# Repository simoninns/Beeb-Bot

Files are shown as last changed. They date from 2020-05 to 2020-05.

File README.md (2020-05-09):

# Beeb-Bot

Beeb-Bot is a fully open-hardware recreation of the 1983 Economatics BBC Buggy robot. The robot was originally designed as a STEM educational tool to accompany the Acorn BBC Microcomputer that was popular in schools at the time.

For full details of the project including printing and assembly instructions, please see the project Wiki:

[Beeb-Bot Project Wiki](https://github.com/simoninns/Beeb-Bot/wiki)

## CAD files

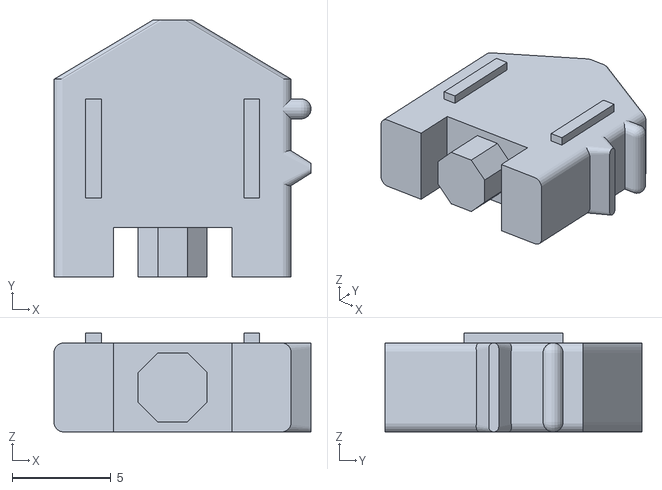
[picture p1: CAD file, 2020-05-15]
stl/mini_switch_plunger.stl
13.0 x 13.0 x 5.00

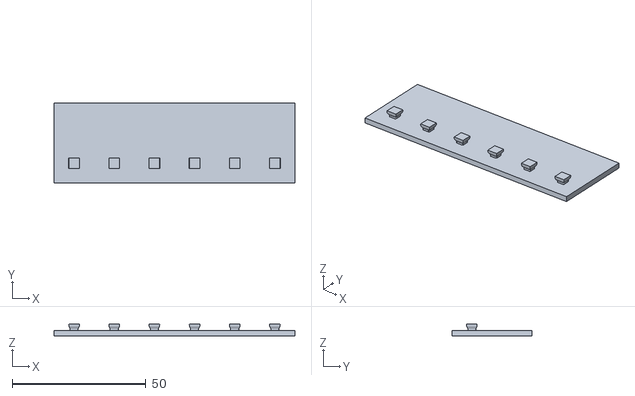
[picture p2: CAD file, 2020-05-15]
stl/plate_sr_30x90mm.stl
90.0 x 30.0 x 4.38

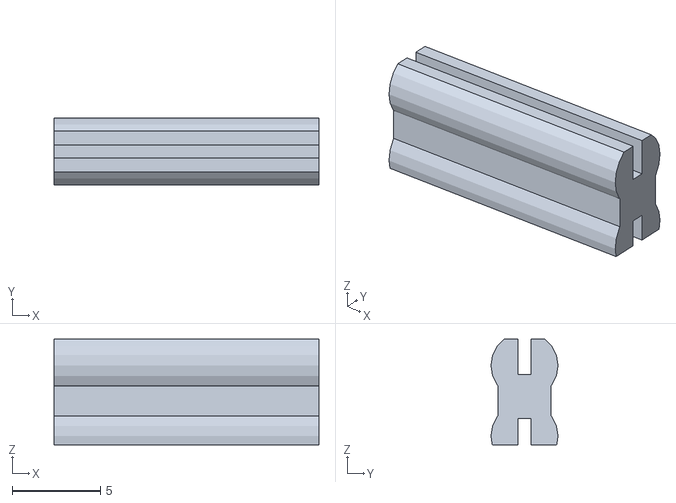
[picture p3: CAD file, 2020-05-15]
stl/link_15mm.stl
15.0 x 3.80 x 6.00

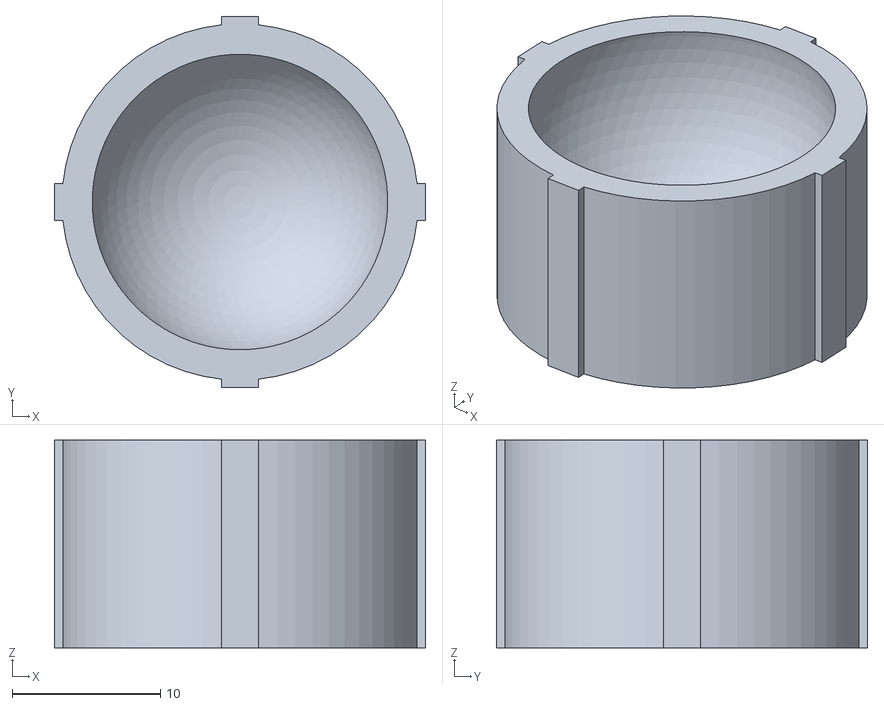
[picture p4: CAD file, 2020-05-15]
stl/ball_caster_top.stl
25.0 x 25.0 x 14.0

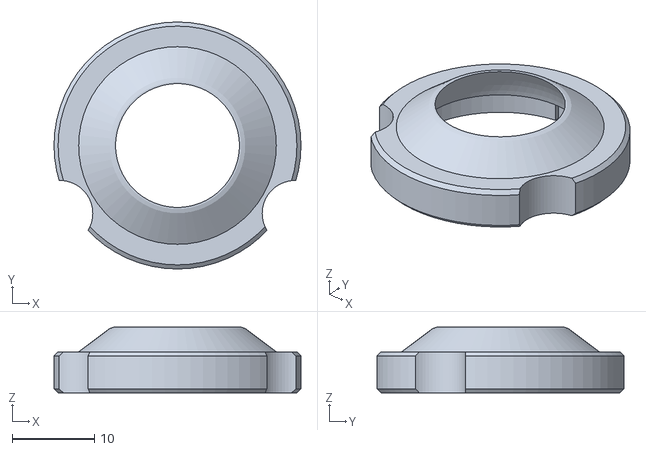
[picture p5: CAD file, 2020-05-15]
stl/ball_caster_base.stl
30.0 x 30.0 x 8.00

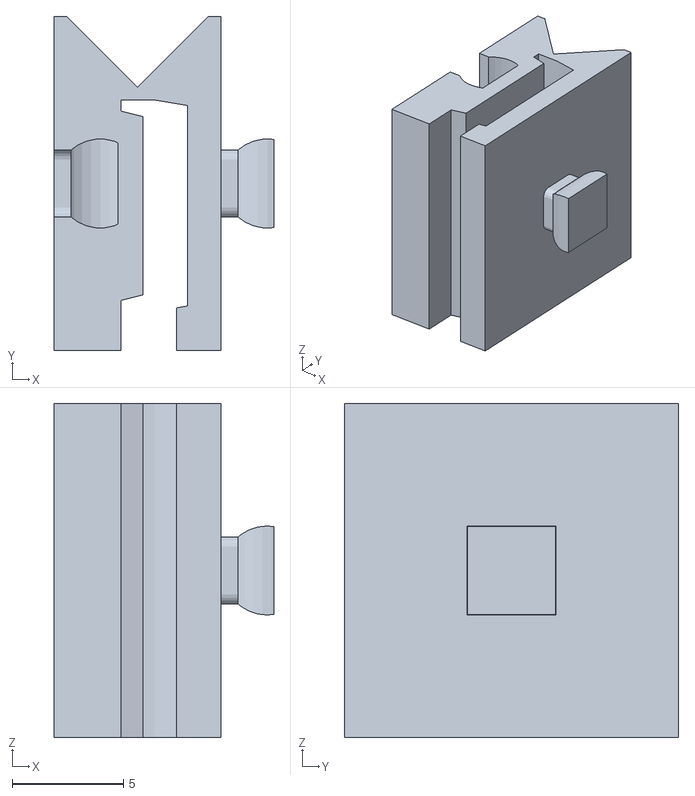
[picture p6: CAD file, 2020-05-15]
stl/hinge_small.stl
9.88 x 15.0 x 15.0

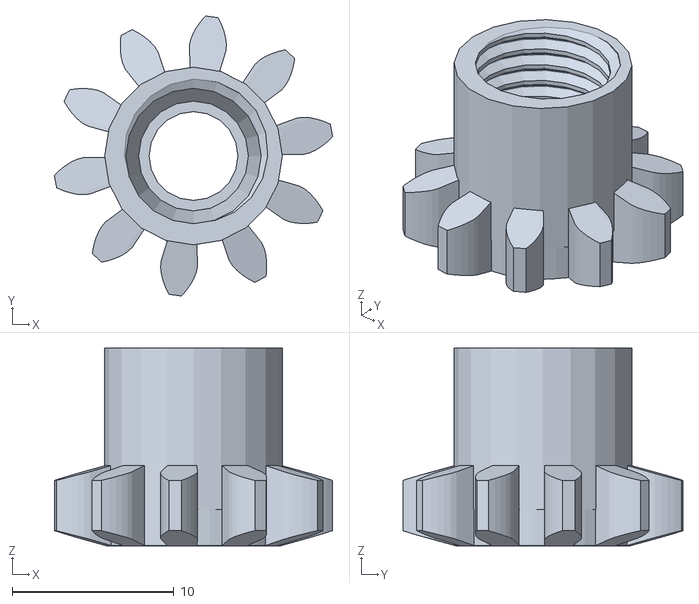
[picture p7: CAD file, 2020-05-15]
stl/nema17_cog_wheel_top.stl
17.2 x 17.3 x 12.2

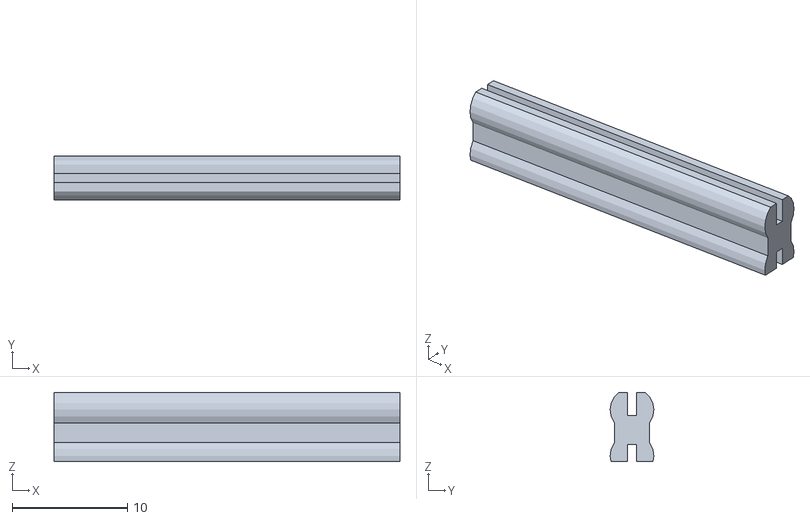
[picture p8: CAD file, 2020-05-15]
stl/link_30mm.stl
30.0 x 3.80 x 6.00

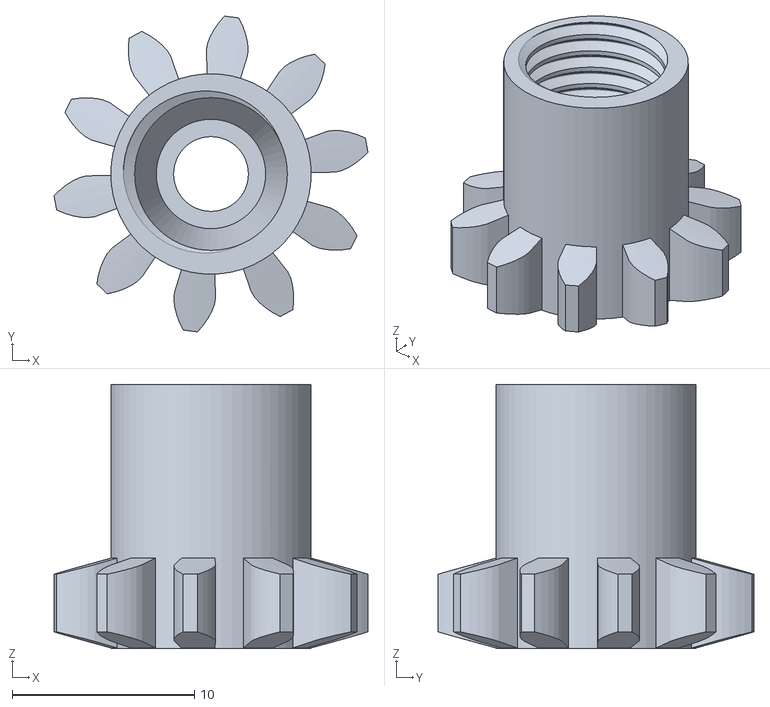
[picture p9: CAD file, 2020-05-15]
stl/philips_cog_wheel_top.stl
17.2 x 17.3 x 14.5

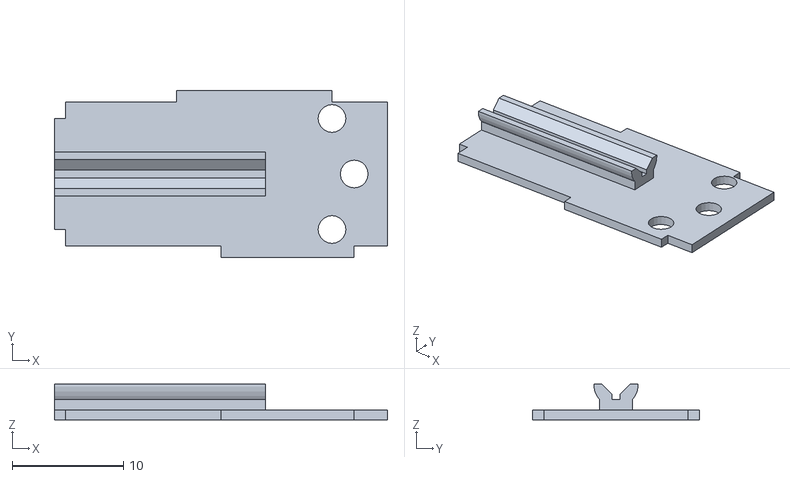
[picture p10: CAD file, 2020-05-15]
stl/mini_switch_top.stl
30.0 x 15.0 x 3.23

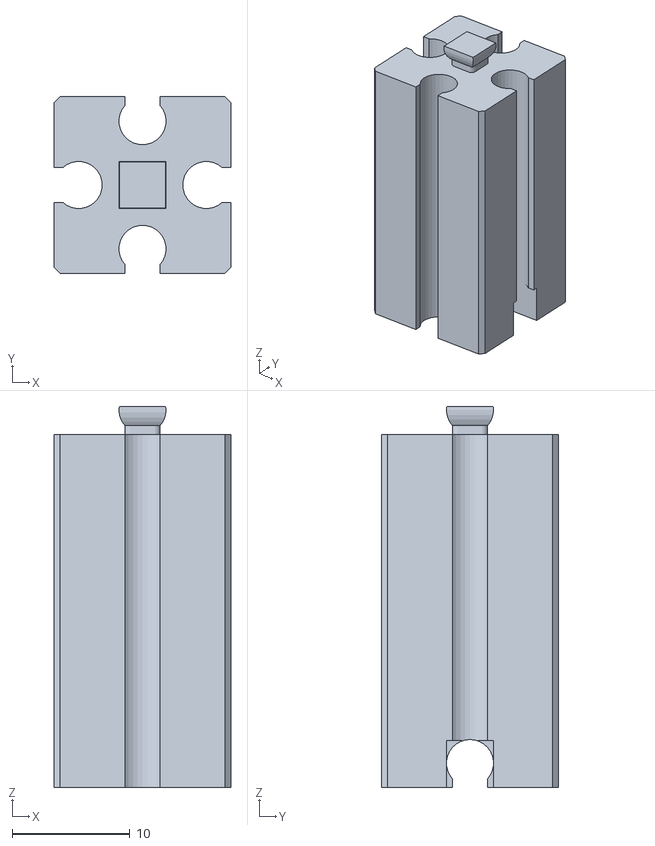
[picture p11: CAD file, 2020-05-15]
stl/block_30mm.stl
15.0 x 15.0 x 32.4

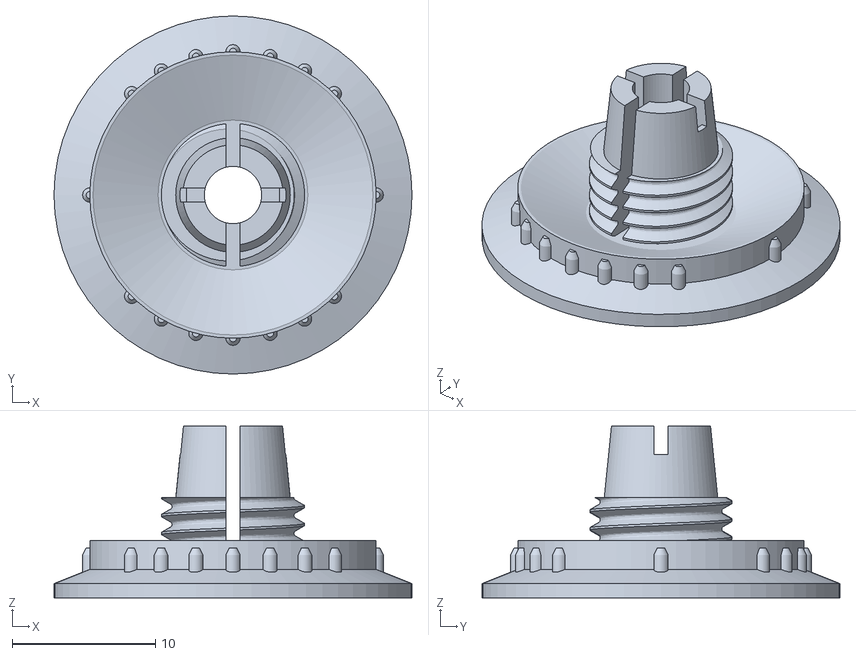
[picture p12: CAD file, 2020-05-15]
stl/hub_bottom.stl
25.0 x 25.0 x 12.0

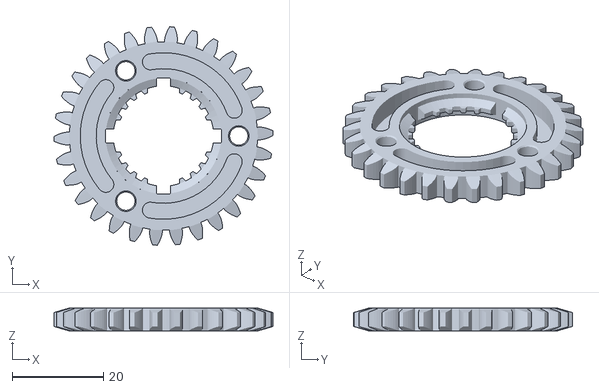
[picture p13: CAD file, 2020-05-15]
stl/gear_wheel.stl
48.0 x 47.9 x 5.00

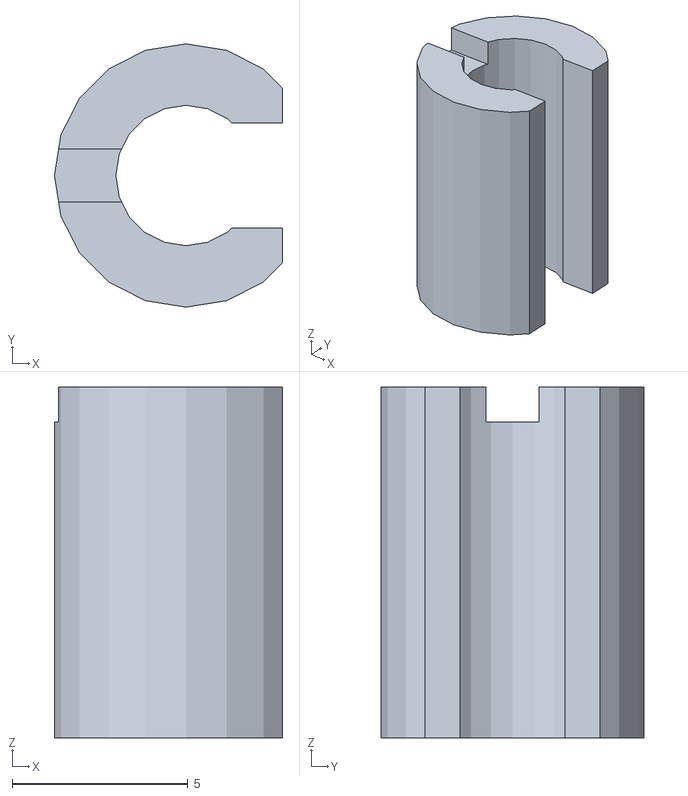
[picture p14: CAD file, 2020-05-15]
stl/clip_10mm.stl
6.50 x 7.50 x 10.0

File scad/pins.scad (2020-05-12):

/************************************************************************

	pins.scad
    
	Beeb-Bot
    Copyright (C) 2020 Simon Inns
    
    This program is free software: you can redistribute it and/or modify
	it under the terms of the GNU General Public License as published by
	the Free Software Foundation, either version 3 of the License, or
	(at your option) any later version.
    
    This program is distributed in the hope that it will be useful,
    but WITHOUT ANY WARRANTY; without even the implied warranty of
    MERCHANTABILITY or FITNESS FOR A PARTICULAR PURPOSE.  See the
    GNU General Public License for more details.
    
    You should have received a copy of the GNU General Public License
    along with this program.  If not, see <http://www.gnu.org/licenses/>.
	
    Email: simon.inns@gmail.com
    
************************************************************************/

include <BOSL/constants.scad>
use <BOSL/transforms.scad>
use <BOSL/shapes.scad>

// Note: The pin is 0.2mm smaller than the pin mask
// So a 4x4 pin is a 4x4 mask, but a 3.8x3.8 pin
module render_pin(xlength, yheight)
{
    move([0,0,-0.125]) {
        difference() {
            union() {
                // Base of pin
                cuboid([xlength -1,3,0.75], fillet=0.5, edges = EDGES_Z_ALL);
            
                // Top of pin
                difference() {
                    move([0,0,1.7]) {
                        difference() {
                            cuboid([xlength,4,4]); // Pin material

                            // Curve x1
                            move([-(xlength / 2) + 2,0,0]) difference() {
                                rotate([90,0,0]) tube(h=4, id=4, od=4 * 2, center=true, $fn=30); // Curve x1
                                move([2,0,0]) cuboid([4,5,10]);
                            }

                            // Curve x1
                            move([(xlength / 2) - 2,0,0]) difference() {
                                rotate([90,0,0]) tube(h=4, id=4, od=4 * 2, center=true, $fn=30); // Curve x1
                                move([-2,0,0]) cuboid([4,5,10]);
                            }
                            
                            rotate([0,90,0]) tube(h=xlength, id=4, od=4 * 2, center=true, $fn=30); // Curve y1
                        }       
                    }
                    move([0,0,2 + yheight]) cuboid([xlength + 2,5,5], center=true); // Flatten the pin
                }
            }

            // Slice the bottom of the pin to prevent overlaying the base
            difference() {
                cuboid([xlength+2,6,0.75], fillet=0.5, edges = EDGES_Z_ALL);
                cuboid([xlength-1,3,1], fillet=0.5, edges = EDGES_Z_ALL);
            }
        }    
    }
}

// Draws a square pin
module square_pin() {
    render() render_pin(4, 2.5);
}

// Draws a square pin mask
module square_pin_mask(xlength, fullHeight) {
    height = fullHeight ? 5:3;
    render() render_pin(xlength, height);

    // Add a small amount to the base to prevent rendering issues
    move([0,0,-0.125 - 0.45]) cuboid([xlength -1,3,0.25], fillet=0.5, edges = EDGES_Z_ALL);
}

// Draws a 15x15xlength column
module column_body(length, cap_mount)
{
        difference() {
            cuboid([15,15,length], chamfer=0.5, edges=EDGES_Z_ALL);

            // Cut out channels
            rotate([0,-90,0]) move([0,0,-7])render() square_pin_mask(length + 4, true);
            rotate([0,90,0]) move([0,0,-7])render() square_pin_mask(length + 4, true);
            rotate([90,90,0]) move([0,0,-7])render() square_pin_mask(length + 4, true);
            rotate([-90,90,0]) move([0,0,-7])render() square_pin_mask(length + 4, true);


            // Recesses to allow attachement of profile caps
            if (cap_mount) {
                move([0,0,(length / 2) + 3 - 5]) cuboid([5,5,6.25], chamfer = 0.5, edges=EDGES_Z_ALL+EDGES_BOTTOM);
                rotate([180,0,0]) move([0,0,(length / 2) + 3 - 5]) cuboid([5,5,6], chamfer = 0.5, edges=EDGES_Z_ALL+EDGES_BOTTOM);
            }
        }
}

// Draws a V-profile joiner as found on the switches and electronic parts
module v_profile(vlength)
{
    difference() {
        rotate([-90,0,0]) move([0,0,0.25]) render_pin(vlength + 3, 2.25);
        move([(vlength / 2) + 1.5,0,0]) cuboid([3,4,4]);
        move([-(vlength / 2) - 1.5,0,0]) cuboid([3,4,4]);
        move([0,2,0]) rotate([45,0,0]) cuboid([vlength + 3, 2, 2]);
        move([0,1,0]) cuboid([vlength + 3, 1, 0.75]);
    }

    move([0,-0.25,0]) cuboid([vlength, 0.5, 3]);
}

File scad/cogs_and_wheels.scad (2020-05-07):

/************************************************************************

	cogs_and_wheels.scad
    
	Beeb-Bot
    Copyright (C) 2020 Simon Inns
    
    This program is free software: you can redistribute it and/or modify
	it under the terms of the GNU General Public License as published by
	the Free Software Foundation, either version 3 of the License, or
	(at your option) any later version.
    
    This program is distributed in the hope that it will be useful,
    but WITHOUT ANY WARRANTY; without even the implied warranty of
    MERCHANTABILITY or FITNESS FOR A PARTICULAR PURPOSE.  See the
    GNU General Public License for more details.
    
    You should have received a copy of the GNU General Public License
    along with this program.  If not, see <http://www.gnu.org/licenses/>.
	
    Email: simon.inns@gmail.com
    
************************************************************************/

include <BOSL/constants.scad>
use <BOSL/transforms.scad>
use <BOSL/shapes.scad>
use <BOSL/involute_gears.scad>
use <BOSL/threading.scad>
use <BOSL/metric_screws.scad>

// Note: The inner hub is common to both the gear_wheel and the large_pulley_wheel
module inner_hub()
{
    rotate([0,0,45]) difference() {
        union() {
            oc1 = 24; // outer diameter
            cir1 = 2 * 3.141 * ((oc1 - 2) / 2);
            nt1 = 24; // number of teeth

            difference() {
                cyl(h=1, d=oc1 - 2);
                gear(mm_per_tooth=cir1/nt1, number_of_teeth=nt1, thickness=2, pressure_angle=25, backlash=0.1, hole_diameter=0, interior=true); 

                rotate([0,0,45]) cuboid([30,5,5]);
                rotate([0,0,-45]) cuboid([30,5,5]);
            }

            move([0,0,0]) tube(h = 5, od=25.5, id=22, center=true);
        }

        move([0,0,1]) cyl(h=1, d1=22, d2=25.5);
        move([0,0,2.5]) cyl(h=2.1, d=25.5);

        rotate([0,180,0]){
            move([0,0,1]) cyl(h=1, d1=22, d2=25.5);
            move([0,0,2.5]) cyl(h=2.1, d=25.5);
        }

        rotate([0,0,45]) cuboid([30,3,6]);
        rotate([0,0,-45]) cuboid([30,3,6]);
    }
}

// Large Pully Wheel - 60mm diameter, 5.5mm height --------------------------------------------------------------------

module render_grey_axle(displayMode)
{
    if (displayMode) {
        rotate([0,0,30]) zrot_copies(rots=[0,60,120,180,240,300], r=33.5 - 16, subrot=true) {
            move([4.5,0,0]) rotate([0,90,0]) cyl(h=15,d=4,fillet2=0.5);
        }
    } else {
        multi = 13; // How many to render
        move([-(((multi-1)*4.5) / 2),0,0]) {
            for(xpos = [0:4.5:((multi-1)*4.5)]) {
                move([xpos,0,0]) cyl(h=15,d=4,fillet2=0.5);
            }
            move([(multi*4) / 2,0,-(15/2) + (1.2/2)]) cuboid([(multi-1)*4.5,0.6,1.2]);
        }
    }
}

module render_large_pulley_wheel()
{
    width = 61.5;
    groove = 4;

    render() difference() {
        union() {
            move([0,0,2]) cyl(h=1,d=width, chamfer1 = 0, chamfer2 = 0.5);
            move([0,0,1]) cyl(h=1, d1=width - groove, d2=width);
            move([0,0,0]) cyl(h=3,d=width - groove);
            move([0,0,-1]) cyl(h=1, d1=width, d2=width - groove);
            move([0,0,-2]) cyl(h=1,d=width, chamfer1 = 0.5, chamfer2 = 0);
        }

        // 6x 4mm holes around the circumference of the gear
        zrot_copies(rots=[0,60,120,180,240,300], r=33/2, subrot=false) {
            zcyl(h=6, d=4);

            // Bevel the top and bottom of the hole
            move([0,0,-2.5]) zcyl(h=.51, d1=5,d2=4);
            move([0,0,2.5]) zcyl(h=.51, d1=4,d2=5);
        }

        zrot_copies(rots=[0,60,120,180,240,300], r=0, subrot=true) {
            arced_slot(d=42 + 2.5, h=7, sd=4, sa=-17.5, ea=17.5);
        }

        // Horizontal holes around the edge of the wheel (30 degree offset from vertical holes)
        rotate([0,0,30]) zrot_copies(rots=[0,60,120,180,240,300], r=39.5 - (15 + 2.5), subrot=true) {
            move([0,0,0]) xcyl(h=15,d=4);
            move([15.5 - 11,0,0]) cuboid([13,3,6]); // Distance is 11mm
            move([7.5,0,0]) cyl(h=6, d=4);
            move([8.5,0,0]) cuboid([2,4,6]);
        }

        // Add hole for inner hub
        cyl(h=6, d=25.5);
    }

    // Render the inner hub
    inner_hub();
}

module large_pulley_wheel(printMode)
{
    $fn=60;

    if (printMode) {
        move([0,0,2.5]) render_large_pulley_wheel();
    } else {
        color("red") render_large_pulley_wheel();
        color("lightgrey") render_grey_axle(true);
    }
}

// The grey axles are decoration pieces that go around the
// outside edge of the large pulley wheel
module grey_axle(printMode)
{
    if (printMode) {
        move([0,0,7.5]) render_grey_axle(false);
    } else {
        color("lightgrey") render_grey_axle(false);
    }
}

// Gear wheel Z30, m 1.5 ----------------------------------------------------------------------------------------------

module render_gear_wheel()
{
    oc1 = 47 - 2; // outer diameter
    cir1 = 2 * 3.1415927 * (oc1 / 2);
    nt1 = 30; // number of teeth
    render() difference() {
        rotate([0,0,7.5]) gear(mm_per_tooth=cir1/nt1, number_of_teeth=nt1, thickness=5, pressure_angle=20, backlash=0.1, hole_diameter=25.5);  

        // 3x 4mm holes around the circumference of the gear
        zrot_copies(rots=[0,120,240], r=33/2, subrot=false) {
            zcyl(h=6, d=4);

            // Bevel the top and bottom of the hole
            move([0,0,-2.5]) zcyl(h=.51, d1=5,d2=4);
            move([0,0,2.5]) zcyl(h=.51, d1=4,d2=5);
        }

        // The arcs are slow to plot, so use render() to speed up preview
        render() move([0,0,6 - 4]) {
            rotate([0,0,20]) arced_slot(d=33, h=7, sd=3.5, sa=0, ea=80);
            rotate([0,0,140]) arced_slot(d=33, h=7, sd=3.5, sa=0, ea=80);
            rotate([0,0,260]) arced_slot(d=33, h=7, sd=3.5, sa=0, ea=80);
        }

        // Upper bevel edge (on gear teeth)
        move([0,0,2]) {
            difference() {
                move([0,0,0.1]) cyl(h=1.1, d=48.25);
                cyl(h=1, d1=48.25, d2=41.35);
                cyl(h=1, d=41.35);
            }
        }

        // Lower bevel edge (on gear teeth)
        rotate([0,180,0]) move([0,0,2]) {
            difference() {
                move([0,0,0.1]) cyl(h=1.1, d=48.25);
                cyl(h=1, d1=48.25, d2=41.35);
                cyl(h=1, d=41.35);
            }
        }
    }

    // Render the inner hub
    inner_hub();
}

module gear_wheel(printMode)
{
    $fn=60;

    if (printMode) {
        move([0,0,2.5]) render_gear_wheel();
    } else {
        color([0.2,0.2,0.2]) render_gear_wheel();
    }
}

// Cog Wheel Z10, m 1.5 with collett ----------------------------------------------------------------------------------

module render_cog_gear()
{
    oc1 = 17 - 2.5; // outer diameter
    cir1 = 2 * 3.1415927 * (oc1 / 2);
    nt1 = 10; // number of teeth
    difference() {
        rotate([0,0,7.5]) gear(mm_per_tooth=cir1/nt1, number_of_teeth=nt1, thickness=5, pressure_angle=20, backlash=0.1, hole_diameter=0);

        move([0,0,2]) {
            difference() {
                move([0,0,0.1]) cyl(h=1.1, d=18);
                cyl(h=1, d1=18, d2=10.75);
                cyl(h=1, d=10.75);
            }
        }

        rotate([0,180,0]) move([0,0,2]) {
            difference() {
                move([0,0,0.1]) cyl(h=1.1, d=18);
                cyl(h=1, d1=18, d2=10.75);
                cyl(h=1, d=10.75);
            }
        }
    }
}

module render_cog_wheel_top()
{
    difference() {
        union() {
            render_cog_gear();
            move([0,0,-4.75]) cyl(h=9.5+5, d=11);
        }

        // add 4mm axle hole
        move([0,0,-5]) cyl(h=20, d=4.1);

        // Add a thread
        move([0,0,-9.25]) threaded_rod(d=9, l=6.1, pitch=get_metric_iso_fine_thread_pitch(9), orient=ORIENT_Z, internal=true);

        // Add profile for the collettes
        move([0,0,-9.25 + 7]) cyl(h=15-6 - 1, d1=8.5, d2=6);
    }
}

// Note: This is the piece designed to fit to the shaft of the original stepper-motors
module cog_wheel_top(printMode)
{
    $fn=60;

    if (printMode) {
        rotate([0,180,0]) move([0,0,-2.5]) render_cog_wheel_top();
    } else {
        color([0.2,0.2,0.2]) render_cog_wheel_top();
    }
}

module render_cog_wheel_bottom()
{
    difference() {
        union() {
            oc1 = 11 - 1; // outer diameter
            cir1 = 2 * 3.1415927 * (oc1 / 2);
            nt1 = 16; // number of teeth

            gear(mm_per_tooth=cir1/nt1, number_of_teeth=nt1, thickness=5, pressure_angle=1, backlash=0.01, hole_diameter=4);
            cyl(h=5,d=9.5);

            move([0,0,-5.5]) threaded_rod(d=9, l=6.0, pitch=get_metric_iso_fine_thread_pitch(9), orient=ORIENT_Z, internal=false);
            move([0,0,-12.5]) cyl(h=8, d2=7.5, d1=6);
        }

        // add 4mm axle hole
        move([0,0,-7]) cyl(h=25, d=4.1);

        // Add split
        move([0,0,-10]) cuboid([1,10,15]);
    }
}
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

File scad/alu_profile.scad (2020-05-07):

/************************************************************************

	alu_profile.scad
    
	Beeb-Bot
    Copyright (C) 2020 Simon Inns
    
    This program is free software: you can redistribute it and/or modify
	it under the terms of the GNU General Public License as published by
	the Free Software Foundation, either version 3 of the License, or
	(at your option) any later version.
    
    This program is distributed in the hope that it will be useful,
    but WITHOUT ANY WARRANTY; without even the implied warranty of
    MERCHANTABILITY or FITNESS FOR A PARTICULAR PURPOSE.  See the
    GNU General Public License for more details.
    
    You should have received a copy of the GNU General Public License
    along with this program.  If not, see <http://www.gnu.org/licenses/>.
	
    Email: simon.inns@gmail.com
    
************************************************************************/

include <BOSL/constants.scad>
use <BOSL/transforms.scad>
use <BOSL/shapes.scad>

include <pins.scad>

// Draws an aluminium profile end cap
// Note: end cap is 1.5mm high to allow for tollerances once
// the piece is assembled (should be 2mm)
module render_single_profile_end_cap()
{
    difference() {
        cuboid([15,15,1.5], chamfer=0.5, edges=EDGES_Z_ALL+EDGES_TOP);

        // Cut out channels
        rotate([0,-90,0]) move([0,0,-7])render() square_pin_mask(5, true);
        rotate([0,90,0]) move([0,0,-7])render() square_pin_mask(5, true);
        rotate([90,90,0]) move([0,0,-7])render() square_pin_mask(5, true);
        rotate([-90,90,0]) move([0,0,-7])render() square_pin_mask(5, true);
    }

    // Add a square pin to the top-side
    move([0,0,1.25]) square_pin();

    // Add a cuboid underneath for attachment to profile
    move([0,0,-3]) cuboid([5,5,5], chamfer = 0.5, edges=EDGES_Z_ALL+EDGES_BOTTOM);
}

// Display either 1 or 28 end caps in 4 rows of 7
module render_profile_end_cap(multiple)
{
    if (multiple < 2) {
        render_single_profile_end_cap();
    } else {
        for (ypos = [0:(multiple / 7) - 1]) {
            for(xpos = [0:(multiple / 4) - 1]) {
                move([xpos * 17,ypos*17,0]) {
                    render_single_profile_end_cap();
                }
            }
        }
    }
}

module render_alu_profile(length)
{
    // Profile length is -4 as profile caps are 2mm thick
    color("lightgrey") render() column_body(length - 4, true);

    color([0.2,0.2,0.2]) move([0,0,(length / 2) - 1]) render() render_profile_end_cap(1);
    color([0.2,0.2,0.2]) rotate([180,0,0]) move([0,0,(length / 2) - 1]) render() render_profile_end_cap(1);
}

module alu_profile15(y_units, printMode)
{
    length = y_units * 15;
    
    if (printMode) {
        // Profile length is -4 as profile caps are 2mm thick

        // Display ready for 3D printing
        move([0,0,(length / 2) - 2]) {
            column_body(length - 4, true);
        }
    } else {
        // Profile length is -4 as profile caps are 2mm thick
        color("lightgrey") render() column_body(length - 4, true);

        // The -.75 moves the end caps to the right position...
        // I need to figure out why this prints 1mm longer than
        // the model (probably due to the tolerance on the underside
        // of the end caps).
        color([0.2,0.2,0.2]) move([0,0,(length / 2) - .75]) render() render_profile_end_cap(1);
        color([0.2,0.2,0.2]) rotate([180,0,0]) move([0,0,(length / 2) - .75]) render() render_profile_end_cap(1);
    }
}

module alu_profile_end_cap(printMode, multiple)
{
    if (printMode) {
        move([0,0,5.5]) render_profile_end_cap(multiple);
    } else {
        color([0.2,0.2,0.2]) move([0,0,5.5]) render_profile_end_cap(multiple);
    }
}

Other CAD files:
stl/cover.stl
stl/ball_caster_holder.stl
stl/alu_profile_120mm.stl
stl/chain_20links.stl
scad/assemblies.scad
scad/BOSL/acme_screws.scad
scad/BOSL/beziers.scad
scad/BOSL/compat.scad
scad/BOSL/constants.scad
scad/BOSL/convex_hull.scad
scad/BOSL/debug.scad
scad/BOSL/involute_gears.scad
scad/BOSL/joiners.scad
scad/BOSL/linear_bearings.scad
scad/BOSL/masks.scad
scad/BOSL/math.scad
scad/BOSL/metric_screws.scad
scad/BOSL/nema_steppers.scad
scad/BOSL/paths.scad
scad/BOSL/phillips_drive.scad
scad/BOSL/quaternions.scad
scad/BOSL/shapes.scad
scad/BOSL/sliders.scad
scad/BOSL/threading.scad
scad/BOSL/torx_drive.scad
scad/BOSL/transforms.scad
scad/BOSL/triangulation.scad
scad/BOSL/wiring.scad
scad/block.scad
scad/caster_ball.scad
scad/chain.scad
scad/cover.scad
scad/diagrams.scad
scad/hinge.scad
scad/hub.scad
scad/link.scad
scad/logo.scad
scad/main.scad
scad/mini_switch.scad
scad/nema17.scad
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

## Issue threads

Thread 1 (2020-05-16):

NEMA17 D and Round shafts

simoninns, 2020-05-16:
Seems like some NEMA17 motors have round shafts, so the 5mm D shaped cog in the project will not fit them.  Should add an alternative part to cover round shaft NEMA17 motors

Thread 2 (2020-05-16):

Slight inwards angle of wheels

simoninns, 2020-05-16:
There is a very slight inward angle of the wheels on the fully 3D printed model.  Looking at the construction the twist seems to be due to the weight on the wheels pivoting slightly over the 15mm/30mm links holding sub-assembly 1 and sub-assembly 3 in place.

The dimensions of the links should be verified as it may be too short on the flat side of the link.

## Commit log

2020-04-25 Set up project structure and add BOSL library files
    [acme_screws.scad, alu_profile.scad, beziers.scad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]
2020-04-25 Added aluminium profile and 15x15 block
    [alu_profile.scad, block.scad, common.scad]
2020-04-26 More parts and improved fit
    [alu_profile.scad, common.scad, main.scad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]
2020-04-27 Added additional parts block 7.5 and corner V15
    [alu_profile.scad, block.scad, common.scad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]
2020-04-27 Added link 15 and link 30
    [block.scad, link.scad, main.scad]
2020-04-27 Added hinge and wheel hub top and base
    [hinge.scad, hub.scad, main.scad]
2020-04-28 Minor fixes and final hub top and base versions
    [alu_profile.scad, hub.scad, main.scad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]
2020-04-28 Better main menu and added gear wheel object
    [cogs_and_wheels.scad, main.scad]
2020-04-29 Improved preview rendering of gear wheel
    [cogs_and_wheels.scad]
2020-04-29 Added large pulley wheel
    [cogs_and_wheels.scad]
2020-04-30 Corrected gear and pulley wheel design
    [cogs_and_wheels.scad]
2020-04-30 Added grey axles for wheel edges
    [cogs_and_wheels.scad, main.scad]
2020-05-01 Added mini-switch design
    [common.scad, main.scad, mini_switch.scad]
2020-05-01 Corrections to switch plunger and link15/link30 parts
    [link.scad, mini_switch.scad]
2020-05-02 Added clip10, V-axle and locking washer parts
    [cogs_and_wheels.scad, main.scad]
2020-05-03 Added caster ball roller and holder parts
    [caster_ball.scad, main.scad]
2020-05-04 Added print-in-place chain design
    [chain.scad, cogs_and_wheels.scad, main.scad]
2020-05-04 Added cog wheel top and bottom parts for motor shafts
    [cogs_and_wheels.scad, main.scad]
2020-05-04 Small correction to non-print display of alu-profiles
    [alu_profile.scad]
2020-05-05 Added mode for mock-up of complete robot assembly
    [cover.scad, main.scad, mini_switch.scad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]
2020-05-05 Added initial design for the top cover
    [cover.scad, mockup.scad]
2020-05-05 Made pin design a little narrower
    [alu_profile.scad, common.scad]
2020-05-06 Fixed print mode and some minor updates. Changed cover design
    [block.scad, caster_ball.scad, chain.scad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]
2020-05-06 Improvements to the customizer menus
    [block.scad, main.scad]
2020-05-06 Improved customizer structure and included assembly steps. Added multiple alu-caps.
    [alu_profile.scad, assemblies.scad, main.scad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]
2020-05-06 Fixed a bug in the pin rendering module
    [common.scad]
2020-05-06 Fix to multiple alu end-caps to decrease print time
    [alu_profile.scad]
2020-05-07 Added block hinge design for sensor mount
    [assemblies.scad, block.scad, hinge.scad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]
2020-05-07 Redesign of pin and pin channel rendering
    [alu_profile.scad, assemblies.scad, block.scad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]
2020-05-09 Added exploded diagrams and updated readme.md
    [assemblies.scad, caster_ball.scad, main.scad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]
2020-05-09 Added exploded diagrams and NEMA 17 motor mount
    [diagrams.scad, main.scad, nema17.scad]
2020-05-10 Added NEMA 17 cog and assembly diagrams
    [assemblies.scad, main.scad, nema17.scad]
2020-05-10 Updated NEMA 17 cog
    [nema17.scad]
2020-05-10 Changed NEMA 17 cog design and started on a new cover design
    [assemblies.scad, cover.scad, main.scad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]
2020-05-10 Additional work on the top cover, added a grill and some cut-outs for ports
    [cover.scad]
2020-05-11 Cover design ready for test printing
    [cover.scad]
2020-05-11 Minor correct and fix to wheel assembly
    [assemblies.scad, cover.scad, nema17.scad]
2020-05-11 Redesigned V-profile pins on mini-switch
    [pins.scad]
2020-05-11 Redesigned top of the cover
    [cover.scad]
2020-05-12 Modified V-profile to loosen the fit a little
    [pins.scad]
2020-05-12 Modified chain design, narrower and slightly shorter
    [chain.scad, main.scad]
2020-05-12 Added a little more shearing strength to the drive chain
    [chain.scad]
2020-05-15 Added Beeb-Bot project logo
    [logo.scad, main.scad]
2020-05-15 Updated ball caster design to raise back of robot by 3mm
    [assemblies.scad, caster_ball.scad]
2020-05-15 Added STL files for all 36 parts
    [alu_profile_120mm.stl, alu_profile_90mm.stl, alu_profile_endcap_x1.stl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]
